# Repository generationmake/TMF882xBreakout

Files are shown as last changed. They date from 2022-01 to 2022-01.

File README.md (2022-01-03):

# TMF882xBreakout
Breakout board for the ams TMF8820, TMF8821 and TMF8828 multi-zone time-of-flight sensors

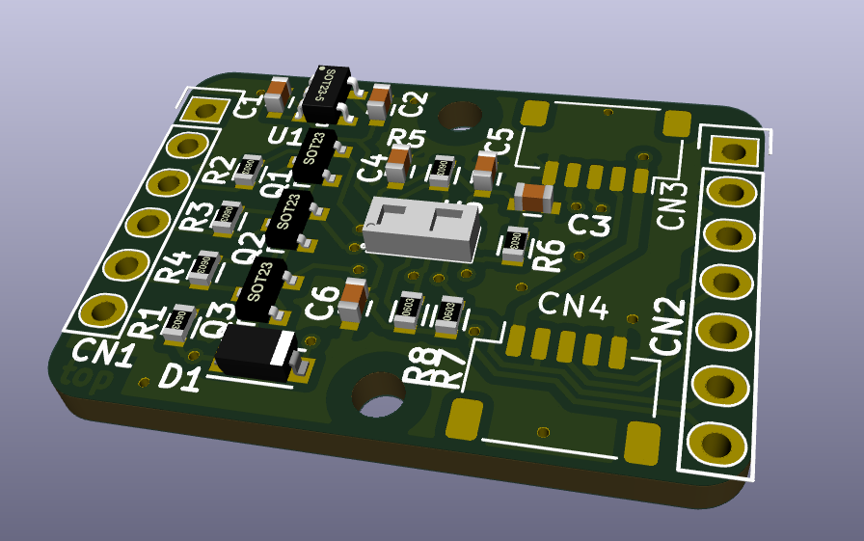
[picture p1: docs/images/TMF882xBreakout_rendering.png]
TMF882xBreakout rendering


## Pinout

### CN1 and CN2

This is a regular 0.1-inch pin header.

| pin number | signal on CN1 | signal on CN2|
|:---:|:---:|:---:|
| 1 | VCC | VCC |
| 2 | GND | GND |
| 3 | I2C_SDA | I2C_SDA |
| 4 | I2C_SCL | I2C_SCL |
| 5 | INT | INT |
| 6 | ENABLE | GPIO0 |
| 7 | not available | GPIO1 |

Several TMF882xBreakout boards can be used by connecting CN1 to CN2 of the previous board. GPIO0 is used to enabled the following TMF882x and thus giving the possibility to change the I2C address of each device one after another.

### CN3 and CN4

This is Arduino ESLOV connector. JST SH 1mm 5-pin.

| pin number | signal on CN3 | signal on CN4|
|:---:|:---:|:---:|
| 1 | VCC | VCC |
| 2 | GND | GND |
| 3 | I2C_SDA | I2C_SDA |
| 4 | I2C_SCL | I2C_SCL |
| 5 | ENABLE | GPIO0 |

Several TMF882xBreakout boards can be used by connecting CN3 to CN4 of the previous board. GPIO0 is used to enabled the following TMF882x and thus giving the possibility to change the I2C address of each device one after another.

This connector does not allow the use of interrupts.

## PCB

### Top

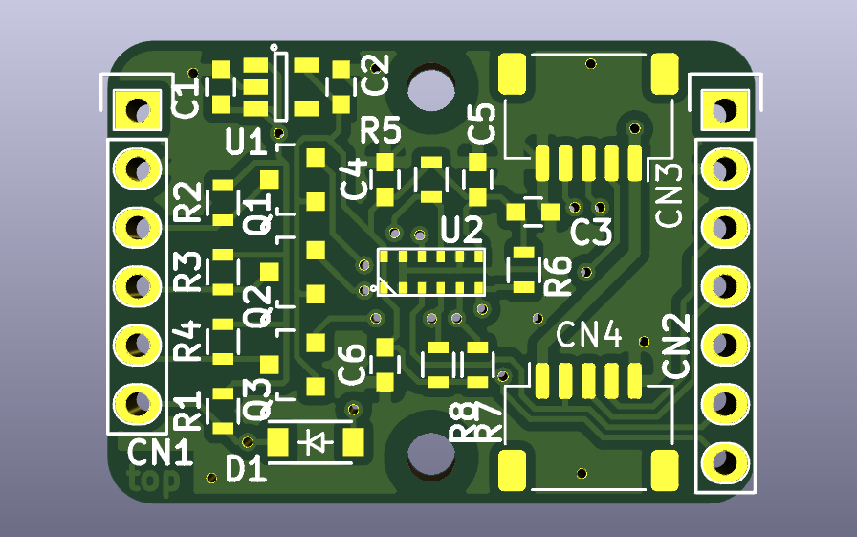
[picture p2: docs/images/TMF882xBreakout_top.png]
TMF882xBreakout PCB top


### Bottom

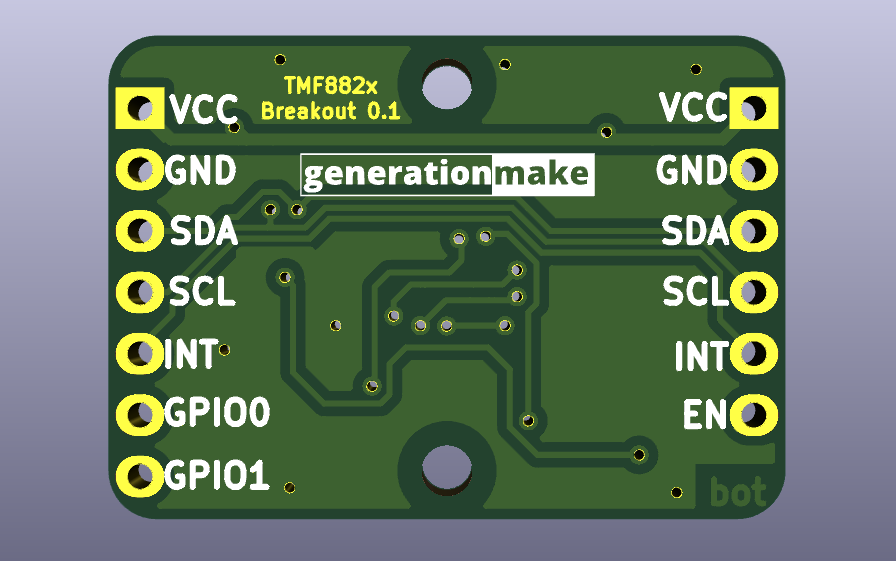
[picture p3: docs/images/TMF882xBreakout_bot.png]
TMF882xBreakout PCB bot


## Resources

### Datasheets

 * https://ams.com/documents/20143/6015057/TMF882X_DS000693_4-00.pdf

### Arduino Libraries

* [107-Arduino-TMF8801](https://github.com/107-systems/107-Arduino-TMF8801)

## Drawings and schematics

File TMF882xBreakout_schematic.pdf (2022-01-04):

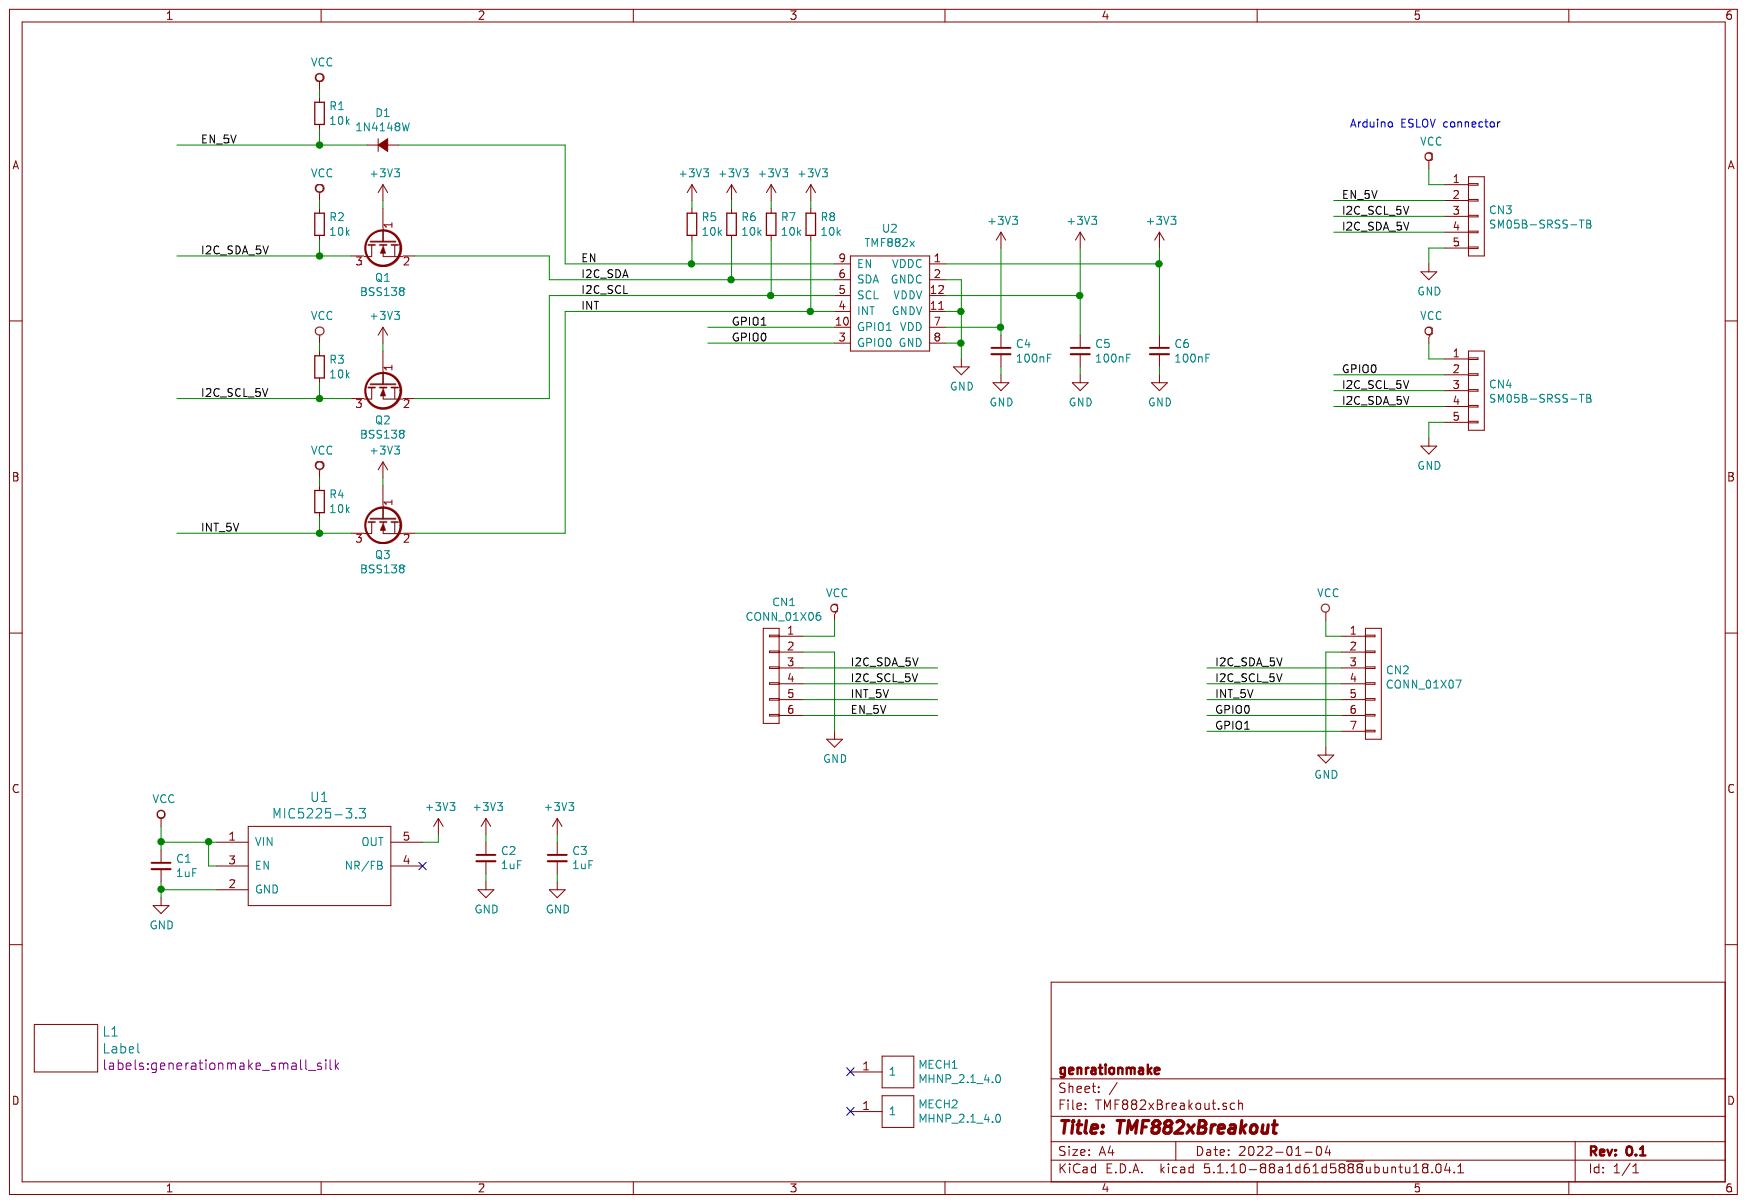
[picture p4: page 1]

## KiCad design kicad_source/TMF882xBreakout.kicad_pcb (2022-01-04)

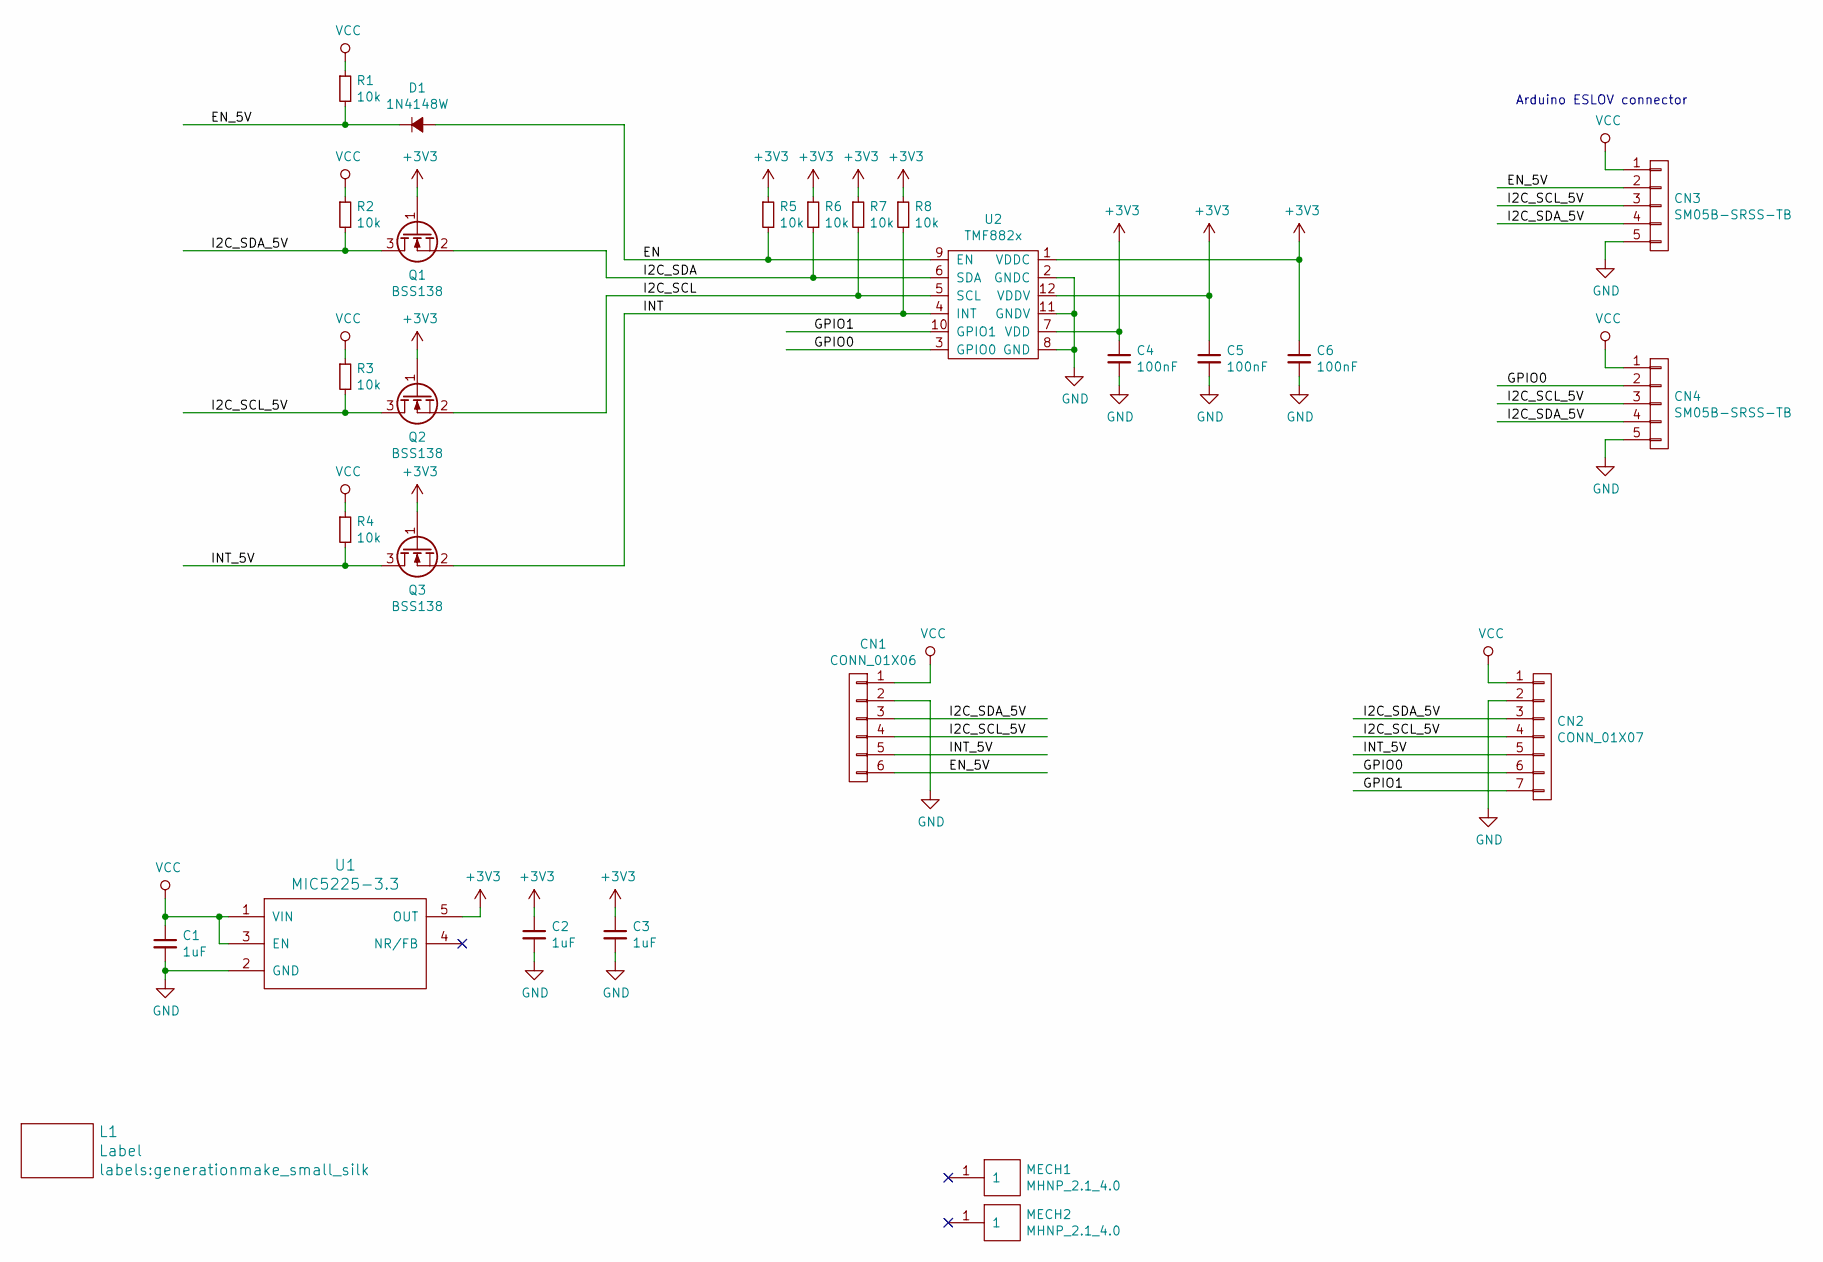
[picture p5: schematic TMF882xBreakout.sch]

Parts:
C1, C2, C3: 1uF; C_0603
C4, C5, C6: 100nF; C_0603
CN1: CONN_01X06; Pin_Header_Straight_1x06
CN2: CONN_01X07; Pin_Header_Straight_1x07
CN3, CN4: SM05B-SRSS-TB; JST_SH_SM05B-SRSS-TB_1x05-1MP_P1.00mm_Horizontal
D1: 1N4148W; SOD-123
L1: Label; generationmake_small_silk
MECH1, MECH2: MHNP_2.1_4.0; MH_210_400_NP
Q1, Q2, Q3: BSS138; SOT-23
R1, R2, R3, R4, R5, R6, R7, R8: 10k; R_0603
U1: MIC5225-3.3; SOT-23-5
U2: TMF882x

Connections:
+3V3: C2.1, C3.1, C4.1, C5.1, C6.1, Q1.1 (G), Q2.1 (G), Q3.1 (G), R5.1, R6.1, R7.1, R8.1, U1.5 (OUT), U2.1 (VDDC), U2.7 (VDD), U2.12 (VDDV)
/EN: D1.2 (A), R5.2, U2.9 (EN)
/EN_5V: CN1.6, CN3.2, D1.1 (K), R1.2
/GPIO0: CN2.6, CN4.2, U2.3 (GPIO0)
/GPIO1: CN2.7, U2.10 (GPIO1)
/I2C_SCL: Q2.2 (S), R7.2, U2.5 (SCL)
/I2C_SCL_5V: CN1.4, CN2.4, CN3.3, CN4.3, Q2.3 (D), R3.2
/I2C_SDA: Q1.2 (S), R6.2, U2.6 (SDA)
/I2C_SDA_5V: CN1.3, CN2.3, CN3.4, CN4.4, Q1.3 (D), R2.2
/INT: Q3.2 (S), R8.2, U2.4 (INT)
/INT_5V: CN1.5, CN2.5, Q3.3 (D), R4.2
GND: C1.2, C2.2, C3.2, C4.2, C5.2, C6.2, CN1.2, CN2.2, CN3.5, CN4.5, U1.2 (GND), U2.2 (GNDC), U2.8 (GND), U2.11 (GNDV)
VCC: C1.1, CN1.1, CN2.1, CN3.1, CN4.1, R1.1, R2.1, R3.1, R4.1, U1.1 (VIN), U1.3 (EN)

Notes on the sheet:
Arduino ESLOV connector

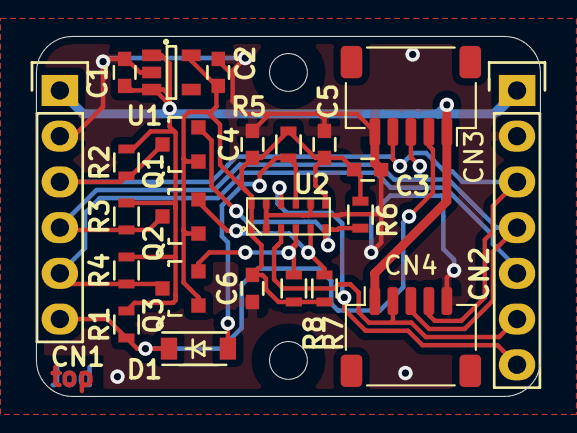
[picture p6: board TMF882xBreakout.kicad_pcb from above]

Board: 2 copper layers, 28.0 x 20.0 mm, 27 parts (1 on the bottom side), 13 nets.

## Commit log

2022-01-03 imported kicad data from TMF8801Breakout
    [TMF882xBreakout.kicad_pcb, TMF882xBreakout.sch]
2022-01-03 updated project, added footprint for TMF882x
    [TMF882xBreakout.kicad_pcb, TMF882xBreakout.sch]
2022-01-04 added schematic pdf and images
    [TMF882xBreakout.kicad_pcb]
